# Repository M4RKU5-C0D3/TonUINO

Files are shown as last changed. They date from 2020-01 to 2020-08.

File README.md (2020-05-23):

# TonUINO
Die DIY Musikbox (nicht nur) für Kinder

# Change Log

## Version 2.1 (xx.xx.xxxx) noch WIP
- Partymodus hat nun eine Queue -> jedes Lied kommt nur genau 1x vorkommt
- Neue Wiedergabe-Modi "Spezialmodus Von-Bis" - Hörspiel, Album und Party -> erlaubt z.B. verschiedene Alben in einem Ordner zu haben und je mit einer Karte zu verknüpfen
- Admin-Menü
- Maximale, Minimale und Initiale Lautstärke
- Karten werden nun über das Admin-Menü neu konfiguriert
- die Funktion der Lautstärketasten (lauter/leiser oder vor/zurück) kann im Adminmenü vertauscht werden
- Shortcuts können konfiguriert werden!
- Support für 5 Knöpfe hinzugefügt
- Reset der Einstellungen ins Adminmenü verschoben
- Modikationskarten (Sleeptimer, Tastensperre, Stopptanz, KiTa-Modus)
- Admin-Menü kann abgesichert werden

## Version 2.01 (01.11.2018)
- kleiner Fix um die Probleme beim Anlernen von Karten zu reduzieren

## Version 2.0 (26.08.2018)

- Lautstärke wird nun über einen langen Tastendruck geändert
- bei kurzem Tastendruck wird der nächste / vorherige Track abgespielt (je nach Wiedergabemodus nicht verfügbar)
- Während der Wiedergabe wird bei langem Tastendruck auf Play/Pause die Nummer des aktuellen Tracks angesagt
- Neuer Wiedergabemodus: **Einzelmodus**
  Eine Karte kann mit einer einzelnen Datei aus einem Ordner verknüpft werden. Dadurch sind theoretisch 25000 verschiedene Karten für je eine Datei möglich
- Neuer Wiedergabemodus: **Hörbuch-Modus**
  Funktioniert genau wie der Album-Modus. Zusätzlich wir der Fortschritt im EEPROM des Arduinos gespeichert und beim nächsten mal wird bei der jeweils letzten Datei neu gestartet. Leider kann nur der Track, nicht die Stelle im Track gespeichert werden
- Um mehr als 100 Karten zu unterstützen wird die Konfiguration der Karten nicht mehr im EEPROM gespeichert sondern direkt auf den Karten - die Karte muss daher beim Anlernen aufgelegt bleiben!
- Durch einen langen Druck auf Play/Pause kann **eine Karte neu konfiguriert** werden
- In den Auswahldialogen kann durch langen Druck auf die Lautstärketasten jeweils um 10 Ordner oder Dateien vor und zurück gesprungen werden
- Reset des MP3 Moduls beim Start entfernt - war nicht nötig und hat "Krach" gemacht

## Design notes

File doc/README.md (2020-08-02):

# LENIBOX

## Einkaufsliste

* [Metall Druckknöpfe](https://www.ebay.de/itm/163190164725) ✔️
* [USB Buchse](https://www.ebay.de/itm/252855078960) ✔️
* [RC522 RFID Modul](https://www.ebay.de/itm/272387195008) ✔️
* ~~[RC522 RFID Karten](https://www.ebay.de/itm/273026026604) ⏰~~
* [RC522 RFID Karten](https://www.reichelt.de/entwicklerboards-rfid-card-fuer-modul-rc522-debo-rfid-card-p201860.html)✔️
* ~~[18650 USB Battery Shield V8](https://www.ebay.de/itm/273652614725) ✔️~~
* [18650 USB Battery Shield V8](https://de.aliexpress.com/item/4000870234968.html) ⏰
* [18650 Akkus](https://www.ebay.de/itm/112787034818) ✔️
* [Drehpotentiometer](https://www.ebay.de/itm/153336494885) ✔️
* [Latstärkeknopf](https://www.ebay.de/itm/333283346990) ✔️
* [Visaton FR 10 HM](https://www.amazon.de/gp/product/B003A65O7U/) ✔️

## Zubehör

* [Lochrasterplatine](https://www.reichelt.de/lochrasterplatine-hartpapier-500x100mm-h25pr500-p8274.html) ✔️
* [Platinen-Steckverbinder](https://www.reichelt.de/platinen-steckverbinder-c7525.html) ✔️
* [Messing Abstandhalter M3](https://www.ebay.de/sch/i.html?_nkw=Messing+M3+Abstandhalter+Set) ✔️
* [Kabel](https://www.ebay.de/itm/302766474820) ✔️
* [Flachsteckhülsen](https://www.ebay.de/itm/152880177973) ✔️

## Datenblätter & Anleitungen

* [TonUINO](https://discourse.voss.earth/t/uebersicht-der-bedienung-tonuino/2072)
* [Visaton FR 10 HM](https://www.visaton.de/de/produkte/chassiszubehoer/breitband-systeme/fr-10-8-ohm)

## Makuna/DFMiniMp3

* "Com Error": [Codes](https://github.com/Makuna/DFMiniMp3/wiki/Notification-Method#static-void-onerroruint16_t-errorcode)

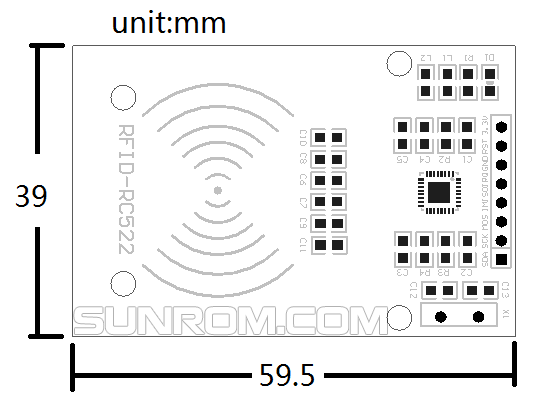
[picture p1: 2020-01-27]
doc/RC522.gif

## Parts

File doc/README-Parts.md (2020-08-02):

# LENIBOX - Bauteile

## Energieversorgung

Beitrag im [Forum](https://discourse.voss.earth/t/tutorial-bau-dir-deine-eigene-powerbank/744)

### Einkaufsliste

0. Step Up: MT3608
0. Lade Bord (USB 5V 1A 18650 Protection) : TC4056A / TP4056 / TP5000 / TP5100
0. Akku
0. Case

## NFC / RFID

### Einkaufsliste

0. Reader (RFID RC522 13,56 MHz MIFARE) : RC522

## MP3

### Einkaufsliste

0. SD Card Board :

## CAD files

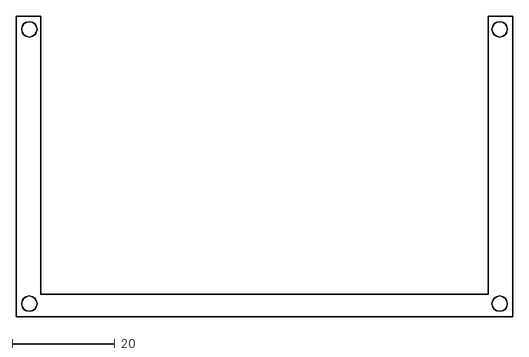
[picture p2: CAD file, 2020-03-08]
cad/card-pocket-lower.dxf
96.5 x 58.4

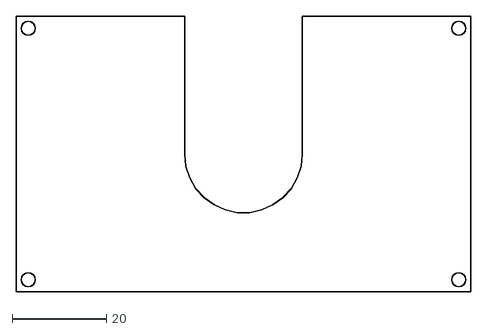
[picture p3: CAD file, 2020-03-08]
cad/card-pocket-upper.dxf
96.5 x 58.4

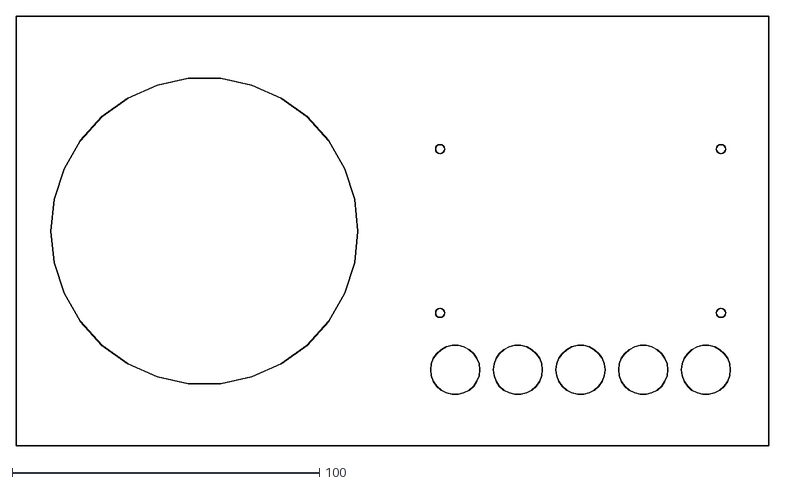
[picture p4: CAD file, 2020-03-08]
cad/front.dxf
245.0 x 140.0

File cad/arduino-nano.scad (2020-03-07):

include <metrics.scad>;

module ARDUINO(){
    color("SteelBlue")cube([17*2.54,7*2.54,1]);
    color("LightGrey")for(X = [2.54/2*3 : 2.54 : 17*2.54-2.54/2*3]){
        translate([X,2.54/2,-3])cylinder(3,0.5,0.5);
    }
}

ARDUINO();

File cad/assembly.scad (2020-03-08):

include <metrics.scad>;

use <card-pocket-lower.scad>
use <card-pocket-upper.scad>
use <pcb.scad>
use <front.scad>

module Assembly(){
  // FRONT
  Front();
  // POCKET
  translate([FW/4*3-PW/2,FH/2-PH/2,FT+0.001]){
    translate([0,0,0])CardPocketLower();
    translate([0,0,PT+0.001])CardPocketUpper();
  }
  // PCB
  translate([FW/4*3-PW/2,FH/2-PH/2,-10]) PCB();
  // BUTTONS
  for(BX = [FW/2+FW/12:FW/12:FW-FW/12]){
    translate([BX,(FH/2-PH/2-FB),0]){
      color("Lime")cylinder(FT+2,FB/2+1,FB/2+1);
      color("LimeGreen")cylinder(FT+4,FB/2-2,FB/2-2);
    }
  }
  // SPEAKER
  color("DimGray")
    translate([(FW/4),(FH/2),0])
      cylinder(1,(FS/2),(FS/2));
}

Assembly();

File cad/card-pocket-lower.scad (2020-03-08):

include <metrics.scad>;

use <card-pocket-upper.scad>;

module CardPocketLower(){
    difference(){
        CardPocketUpper();
        //CUTOUT
        translate([(PW-CW-PP)/2,PH-CH,-1])cube([CW+2,CH+1,PT+PP]);
    }
}

projection(cut = true)CardPocketLower();

echo(str("CardPocketLower: ",PW,"x",PH,"x",PT,"mm"));

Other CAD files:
cad/card-pocket-upper.scad
cad/front.scad
cad/metrics.scad
cad/pcb.scad

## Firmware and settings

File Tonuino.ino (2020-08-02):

#include <DFMiniMp3.h>
#include <EEPROM.h>
#include <JC_Button.h>
#include <MFRC522.h>
#include <SPI.h>
#include <SoftwareSerial.h>
#include <avr/sleep.h>

/*
   _____         _____ _____ _____ _____
  |_   _|___ ___|  |  |     |   | |     |
    | | | . |   |  |  |-   -| | | |  |  |
    |_| |___|_|_|_____|_____|_|___|_____|
    TonUINO Version 2.1

    created by Thorsten Voß and licensed under GNU/GPL.
    Information and contribution at https://tonuino.de.
*/

// uncomment the below line to enable five button support
//#define FIVEBUTTONS

static const uint32_t cardCookie = 322417479;

// DFPlayer Mini
SoftwareSerial mySoftwareSerial(2, 3); // RX, TX
uint16_t numTracksInFolder;
uint16_t currentTrack;
uint16_t firstTrack;
uint8_t queue[255];
uint8_t volume;

struct folderSettings {
  uint8_t folder;
  uint8_t mode;
  uint8_t special;
  uint8_t special2;
};

// this object stores nfc tag data
struct nfcTagObject {
  uint32_t cookie;
  uint8_t version;
  folderSettings nfcFolderSettings;
  //  uint8_t folder;
  //  uint8_t mode;
  //  uint8_t special;
  //  uint8_t special2;
};

// admin settings stored in eeprom
struct adminSettings {
  uint32_t cookie;
  byte version;
  uint8_t maxVolume;
  uint8_t minVolume;
  uint8_t initVolume;
  uint8_t eq;
  bool locked;
  long standbyTimer;
  bool invertVolumeButtons;
  folderSettings shortCuts[4];
  uint8_t adminMenuLocked;
  uint8_t adminMenuPin[4];
};

adminSettings mySettings;
nfcTagObject myCard;
folderSettings *myFolder;
unsigned long sleepAtMillis = 0;
static uint16_t _lastTrackFinished;

static void nextTrack(uint16_t track);
uint8_t voiceMenu(int numberOfOptions, int startMessage, int messageOffset,
                  bool preview = false, int previewFromFolder = 0, int defaultValue = 0, bool exitWithLongPress = false);
bool isPlaying();
bool checkTwo ( uint8_t a[], uint8_t b[] );
void writeCard(nfcTagObject nfcTag);
void dump_byte_array(byte * buffer, byte bufferSize);
void adminMenu(bool fromCard = false);
bool knownCard = false;

// implement a notification class,
// its member methods will get called
//
class Mp3Notify {
  public:
    static void OnError(uint16_t errorCode) {
      // see DfMp3_Error for code meaning
      Serial.println();
      Serial.print("Com Error ");
      Serial.println(errorCode);
    }
    static void PrintlnSourceAction(DfMp3_PlaySources source, const char* action) {
      if (source & DfMp3_PlaySources_Sd) Serial.print("SD Karte ");
      if (source & DfMp3_PlaySources_Usb) Serial.print("USB ");
      if (source & DfMp3_PlaySources_Flash) Serial.print("Flash ");
      Serial.println(action);
    }
    static void OnPlayFinished(DfMp3_PlaySources source, uint16_t track) {
      //      Serial.print("Track beendet");
      //      Serial.println(track);
      //      delay(100);
      nextTrack(track);
    }
    static void OnPlaySourceOnline(DfMp3_PlaySources source) {
      PrintlnSourceAction(source, "online");
    }
    static void OnPlaySourceInserted(DfMp3_PlaySources source) {
      PrintlnSourceAction(source, "bereit");
    }
    static void OnPlaySourceRemoved(DfMp3_PlaySources source) {
      PrintlnSourceAction(source, "entfernt");
    }
};

static DFMiniMp3<SoftwareSerial, Mp3Notify> mp3(mySoftwareSerial);

void shuffleQueue() {
  // Queue für die Zufallswiedergabe erstellen
  for (uint8_t x = 0; x < numTracksInFolder - firstTrack + 1; x++)
    queue[x] = x + firstTrack;
  // Rest mit 0 auffüllen
  for (uint8_t x = numTracksInFolder - firstTrack + 1; x < 255; x++)
    queue[x] = 0;
  // Queue mischen
  for (uint8_t i = 0; i < numTracksInFolder - firstTrack + 1; i++)
  {
    uint8_t j = random (0, numTracksInFolder - firstTrack + 1);
    uint8_t t = queue[i];
    queue[i] = queue[j];
    queue[j] = t;
  }
  /*  Serial.println(F("Queue :"));
    for (uint8_t x = 0; x < numTracksInFolder - firstTrack + 1 ; x++)
      Serial.println(queue[x]);
  */
}

void writeSettingsToFlash() {
  Serial.println(F("=== writeSettingsToFlash()"));
  int address = sizeof(myFolder->folder) * 100;
  EEPROM.put(address, mySettings);
}

void resetSettings() {
  Serial.println(F("=== resetSettings()"));
  mySettings.cookie = cardCookie;
  mySettings.version = 2;
  mySettings.maxVolume = 25;
  mySettings.minVolume = 5;
  mySettings.initVolume = 15;
  mySettings.eq = 1;
  mySettings.locked = false;
  mySettings.standbyTimer = 0;
  mySettings.invertVolumeButtons = true;
  mySettings.shortCuts[0].folder = 0;
  mySettings.shortCuts[1].folder = 0;
  mySettings.shortCuts[2].folder = 0;
  mySettings.shortCuts[3].folder = 0;
  mySettings.adminMenuLocked = 0;
  mySettings.adminMenuPin[0] = 1;
  mySettings.adminMenuPin[1] = 1;
  mySettings.adminMenuPin[2] = 1;
  mySettings.adminMenuPin[3] = 1;

  writeSettingsToFlash();
}

void migrateSettings(int oldVersion) {
  if (oldVersion == 1) {
    Serial.println(F("=== resetSettings()"));
    Serial.println(F("1 -> 2"));
    mySettings.version = 2;
    mySettings.adminMenuLocked = 0;
    mySettings.adminMenuPin[0] = 1;
    mySettings.adminMenuPin[1] = 1;
    mySettings.adminMenuPin[2] = 1;
    mySettings.adminMenuPin[3] = 1;
    writeSettingsToFlash();
  }
}

void loadSettingsFromFlash() {
  Serial.println(F("=== loadSettingsFromFlash()"));
  int address = sizeof(myFolder->folder) * 100;
  EEPROM.get(address, mySettings);
  if (mySettings.cookie != cardCookie)
    resetSettings();
  migrateSettings(mySettings.version);

  Serial.print(F("Version: "));
  Serial.println(mySettings.version);

  Serial.print(F("Maximal Volume: "));
  Serial.println(mySettings.maxVolume);

  Serial.print(F("Minimal Volume: "));
  Serial.println(mySettings.minVolume);

  Serial.print(F("Initial Volume: "));
  Serial.println(mySettings.initVolume);

  Serial.print(F("EQ: "));
  Serial.println(mySettings.eq);

  Serial.print(F("Locked: "));
  Serial.println(mySettings.locked);

  Serial.print(F("Sleep Timer: "));
  Serial.println(mySettings.standbyTimer);

  Serial.print(F("Inverted Volume Buttons: "));
  Serial.println(mySettings.invertVolumeButtons);

  Serial.print(F("Admin Menu locked: "));
  Serial.println(mySettings.adminMenuLocked);

  Serial.print(F("Admin Menu Pin: "));
  Serial.print(mySettings.adminMenuPin[0]);
  Serial.print(mySettings.adminMenuPin[1]);
  Serial.print(mySettings.adminMenuPin[2]);
  Serial.println(mySettings.adminMenuPin[3]);
}

class Modifier {
  public:
    virtual void loop() {}
    virtual bool handlePause() {
      return false;
    }
    virtual bool handleNext() {
      return false;
    }
    virtual bool handlePrevious() {
      return false;
    }
    virtual bool handleNextButton() {
      return false;
    }
    virtual bool handlePreviousButton() {
      return false;
    }
    virtual bool handleVolumeUp() {
      return false;
    }
    virtual bool handleVolumeDown() {
      return false;
    }
    virtual bool handleRFID(nfcTagObject *newCard) {
      return false;
    }
    virtual uint8_t getActive() {
      return 0;
    }
    Modifier() {

    }
};

Modifier *activeModifier = NULL;

class SleepTimer: public Modifier {
  private:
    unsigned long sleepAtMillis = 0;

  public:
    void loop() {
      if (this->sleepAtMillis != 0 && millis() > this->sleepAtMillis) {
        Serial.println(F("=== SleepTimer::loop() -> SLEEP!"));
        mp3.pause();
        setstandbyTimer();
        activeModifier = NULL;
        delete this;
      }
    }

    SleepTimer(uint8_t minutes) {
      Serial.println(F("=== SleepTimer()"));
      Serial.println(minutes);
      this->sleepAtMillis = millis() + minutes * 60000;
      //      if (isPlaying())
      //        mp3.playAdvertisement(302);
      //      delay(500);
    }
    uint8_t getActive() {
      Serial.println(F("== SleepTimer::getActive()"));
      return 1;
    }
};

class FreezeDance: public Modifier {
  private:
    unsigned long nextStopAtMillis = 0;
    const uint8_t minSecondsBetweenStops = 5;
    const uint8_t maxSecondsBetweenStops = 30;

    void setNextStopAtMillis() {
      uint16_t seconds = random(this->minSecondsBetweenStops, this->maxSecondsBetweenStops + 1);
      Serial.println(F("=== FreezeDance::setNextStopAtMillis()"));
      Serial.println(seconds);
      this->nextStopAtMillis = millis() + seconds * 1000;
    }

  public:
    void loop() {
      if (this->nextStopAtMillis != 0 && millis() > this->nextStopAtMillis) {
        Serial.println(F("== FreezeDance::loop() -> FREEZE!"));
        if (isPlaying()) {
          mp3.playAdvertisement(301);
          delay(500);
        }
        setNextStopAtMillis();
      }
    }
    FreezeDance(void) {
      Serial.println(F("=== FreezeDance()"));
      if (isPlaying()) {
        delay(1000);
        mp3.playAdvertisement(300);
        delay(500);
      }
      setNextStopAtMillis();
    }
    uint8_t getActive() {
      Serial.println(F("== FreezeDance::getActive()"));
      return 2;
    }
};

class Locked: public Modifier {
  public:
    virtual bool handlePause()     {
      Serial.println(F("== Locked::handlePause() -> LOCKED!"));
      return true;
    }
    virtual bool handleNextButton()       {
      Serial.println(F("== Locked::handleNextButton() -> LOCKED!"));
      return true;
    }
    virtual bool handlePreviousButton() {
      Serial.println(F("== Locked::handlePreviousButton() -> LOCKED!"));
      return true;
    }
    virtual bool handleVolumeUp()   {
      Serial.println(F("== Locked::handleVolumeUp() -> LOCKED!"));
      return true;
    }
    virtual bool handleVolumeDown() {
      Serial.println(F("== Locked::handleVolumeDown() -> LOCKED!"));
      return true;
    }
    virtual bool handleRFID(nfcTagObject *newCard) {
      Serial.println(F("== Locked::handleRFID() -> LOCKED!"));
      return true;
    }
    Locked(void) {
      Serial.println(F("=== Locked()"));
      //      if (isPlaying())
      //        mp3.playAdvertisement(303);
    }
    uint8_t getActive() {
      return 3;
    }
};

class ToddlerMode: public Modifier {
  public:
    virtual bool handlePause()     {
      Serial.println(F("== ToddlerMode::handlePause() -> LOCKED!"));
      return true;
    }
    virtual bool handleNextButton()       {
      Serial.println(F("== ToddlerMode::handleNextButton() -> LOCKED!"));
      return true;
    }
    virtual bool handlePreviousButton() {
      Serial.println(F("== ToddlerMode::handlePreviousButton() -> LOCKED!"));
      return true;
    }
    virtual bool handleVolumeUp()   {
      Serial.println(F("== ToddlerMode::handleVolumeUp() -> LOCKED!"));
      return true;
    }
    virtual bool handleVolumeDown() {
      Serial.println(F("== ToddlerMode::handleVolumeDown() -> LOCKED!"));
      return true;
    }
    ToddlerMode(void) {
      Serial.println(F("=== ToddlerMode()"));
      //      if (isPlaying())
      //        mp3.playAdvertisement(304);
    }
    uint8_t getActive() {
      Serial.println(F("== ToddlerMode::getActive()"));
      return 4;
    }
};

class KindergardenMode: public Modifier {
  private:
    nfcTagObject nextCard;
    bool cardQueued = false;

  public:
    virtual bool handleNext() {
      Serial.println(F("== KindergardenMode::handleNext() -> NEXT"));
      //if (this->nextCard.cookie == cardCookie && this->nextCard.nfcFolderSettings.folder != 0 && this->nextCard.nfcFolderSettings.mode != 0) {
      //myFolder = &this->nextCard.nfcFolderSettings;
      if (this->cardQueued == true) {
        this->cardQueued = false;

        myCard = nextCard;
        myFolder = &myCard.nfcFolderSettings;
        Serial.println(myFolder->folder);
        Serial.println(myFolder->mode);
        playFolder();
        return true;
      }
      return false;
    }
    //    virtual bool handlePause()     {
    //      Serial.println(F("== KindergardenMode::handlePause() -> LOCKED!"));
    //      return true;
    //    }
    virtual bool handleNextButton()       {
      Serial.println(F("== KindergardenMode::handleNextButton() -> LOCKED!"));
      return true;
    }
    virtual bool handlePreviousButton() {
      Serial.println(F("== KindergardenMode::handlePreviousButton() -> LOCKED!"));
      return true;
    }
    virtual bool handleRFID(nfcTagObject * newCard) { // lot of work to do!
      Serial.println(F("== KindergardenMode::handleRFID() -> queued!"));
      this->nextCard = *newCard;
      this->cardQueued = true;
      if (!isPlaying()) {
        handleNext();
      }
      return true;
    }
    KindergardenMode() {
      Serial.println(F("=== KindergardenMode()"));
      //      if (isPlaying())
      //        mp3.playAdvertisement(305);
      //      delay(500);
    }
    uint8_t getActive() {
      Serial.println(F("== KindergardenMode::getActive()"));
      return 5;
    }
};

class RepeatSingleModifier: public Modifier {
  public:
    virtual bool handleNext() {
      Serial.println(F("== RepeatSingleModifier::handleNext() -> REPEAT CURRENT TRACK"));
      delay(50);
      if (isPlaying()) return true;
      mp3.playFolderTrack(myFolder->folder, currentTrack);
      _lastTrackFinished = 0;
      return true;
    }
    RepeatSingleModifier() {
      Serial.println(F("=== RepeatSingleModifier()"));
    }
    uint8_t getActive() {
      Serial.println(F("== RepeatSingleModifier::getActive()"));
      return 6;
    }
};

// An modifier can also do somethings in addition to the modified action
// by returning false (not handled) at the end
// This simple FeedbackModifier will tell the volume before changing it and
// give some feedback once a RFID card is detected.
class FeedbackModifier: public Modifier {
  public:
    virtual bool handleVolumeDown() {
      if (volume > mySettings.minVolume) {
        mp3.playAdvertisement(volume - 1);
      }
      else {
        mp3.playAdvertisement(volume);
      }
      delay(500);
      Serial.println(F("== FeedbackModifier::handleVolumeDown()!"));
      return false;
    }
    virtual bool handleVolumeUp() {
      if (volume < mySettings.maxVolume) {
        mp3.playAdvertisement(volume + 1);
      }
      else {
        mp3.playAdvertisement(volume);
      }
      delay(500);
      Serial.println(F("== FeedbackModifier::handleVolumeUp()!"));
      return false;
    }
    virtual bool handleRFID(nfcTagObject *newCard) {
      Serial.println(F("== FeedbackModifier::handleRFID()"));
      return false;
    }
};
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
void loop() {
  do {
    checkStandbyAtMillis();
    mp3.loop();

    // Modifier : WIP!
    if (activeModifier != NULL) {
      activeModifier->loop();
    }

    // Buttons werden nun über JS_Button gehandelt, dadurch kann jede Taste
    // doppelt belegt werden
    readButtons();

    volumeAnalogKnob();

    // admin menu
    if ((pauseButton.pressedFor(LONG_PRESS) || upButton.pressedFor(LONG_PRESS) || downButton.pressedFor(LONG_PRESS)) && pauseButton.isPressed() && upButton.isPressed() && downButton.isPressed()) {
      mp3.pause();
      do {
        readButtons();
      } while (pauseButton.isPressed() || upButton.isPressed() || downButton.isPressed());
      readButtons();
      adminMenu();
      break;
    }

    if (pauseButton.wasReleased()) {
      if (activeModifier != NULL)
        if (activeModifier->handlePause() == true)
          return;
      if (ignorePauseButton == false)
        if (isPlaying()) {
          mp3.pause();
          setstandbyTimer();
        }
        else if (knownCard) {
          mp3.start();
          disablestandbyTimer();
        }
      ignorePauseButton = false;
    } else if (pauseButton.pressedFor(LONG_PRESS) &&
               ignorePauseButton == false) {
      if (activeModifier != NULL)
        if (activeModifier->handlePause() == true)
          return;
      if (isPlaying()) {
        uint8_t advertTrack;
        if (myFolder->mode == 3 || myFolder->mode == 9) {
          advertTrack = (queue[currentTrack - 1]);
        }
        else {
          advertTrack = currentTrack;
        }
        // Spezialmodus Von-Bis für Album und Party gibt die Dateinummer relativ zur Startposition wieder
        if (myFolder->mode == 8 || myFolder->mode == 9) {
          advertTrack = advertTrack - myFolder->special + 1;
        }
        mp3.playAdvertisement(advertTrack);
      }
      else {
        playShortCut(0);
      }
      ignorePauseButton = true;
    }

    if (upButton.pressedFor(LONG_PRESS)) {
#ifndef FIVEBUTTONS
      if (isPlaying()) {
        if (!mySettings.invertVolumeButtons) {
          volumeUpButton();
        }
        else {
          nextButton();
        }
      }
      else {
        playShortCut(1);
      }
      ignoreUpButton = true;
#endif
    } else if (upButton.wasReleased()) {
      if (!ignoreUpButton)
        if (!mySettings.invertVolumeButtons) {
          nextButton();
        }
        else {
          volumeUpButton();
        }
      ignoreUpButton = false;
    }

    if (downButton.pressedFor(LONG_PRESS)) {
#ifndef FIVEBUTTONS
      if (isPlaying()) {
        if (!mySettings.invertVolumeButtons) {
          volumeDownButton();
        }
        else {
          previousButton();
        }
      }
      else {
        playShortCut(2);
      }
      ignoreDownButton = true;
#endif
    } else if (downButton.wasReleased()) {
      if (!ignoreDownButton) {
        if (!mySettings.invertVolumeButtons) {
          previousButton();
        }
        else {
          volumeDownButton();
        }
      }
      ignoreDownButton = false;
    }
#ifdef FIVEBUTTONS
    if (buttonFour.wasReleased()) {
      if (isPlaying()) {
        if (!mySettings.invertVolumeButtons) {
          volumeUpButton();
        }
        else {
          nextButton();
        }
      }
      else {
        playShortCut(1);
      }
    }
    if (buttonFive.wasReleased()) {
      if (isPlaying()) {
        if (!mySettings.invertVolumeButtons) {
          volumeDownButton();
        }
        else {
          previousButton();
        }
      }
      else {
        playShortCut(2);
      }
    }
#endif
    // Ende der Buttons
  } while (!mfrc522.PICC_IsNewCardPresent());

  // RFID Karte wurde aufgelegt

  if (!mfrc522.PICC_ReadCardSerial())
    return;

  if (readCard(&myCard) == true) {
    if (myCard.cookie == cardCookie && myCard.nfcFolderSettings.folder != 0 && myCard.nfcFolderSettings.mode != 0) {
      playFolder();
    }

    // Neue Karte konfigurieren
    else if (myCard.cookie != cardCookie) {
      knownCard = false;
      mp3.playMp3FolderTrack(300);
      waitForTrackToFinish();
      setupCard();
    }
  }
  mfrc522.PICC_HaltA();
  mfrc522.PCD_StopCrypto1();

}

void adminMenu(bool fromCard = false) {
  disablestandbyTimer();
  mp3.pause();
  Serial.println(F("=== adminMenu()"));
  knownCard = false;
  if (fromCard == false) {
    // Admin menu has been locked - it still can be trigged via admin card
    if (mySettings.adminMenuLocked == 1) {
      return;
    }
    // Pin check
    else if (mySettings.adminMenuLocked == 2) {
      uint8_t pin[4];
      mp3.playMp3FolderTrack(991);
      if (askCode(pin) == true) {
        if (checkTwo(pin, mySettings.adminMenuPin) == false) {
          return;
        }
      } else {
        return;
      }
    }
    // Match check
    else if (mySettings.adminMenuLocked == 3) {
      uint8_t a = random(10, 20);
      uint8_t b = random(1, 10);
      uint8_t c;
      mp3.playMp3FolderTrack(992);
      waitForTrackToFinish();
      mp3.playMp3FolderTrack(a);

      if (random(1, 3) == 2) {
        // a + b
        c = a + b;
        waitForTrackToFinish();
        mp3.playMp3FolderTrack(993);
      } else {
        // a - b
        b = random(1, a);
        c = a - b;
        waitForTrackToFinish();
        mp3.playMp3FolderTrack(994);
      }
      waitForTrackToFinish();
      mp3.playMp3FolderTrack(b);
      Serial.println(c);
      uint8_t temp = voiceMenu(255, 0, 0, false);
      if (temp != c) {
        return;
      }
    }
  }
  int subMenu = voiceMenu(12, 900, 900, false, false, 0, true);
  if (subMenu == 0)
    return;
  if (subMenu == 1) {
    resetCard();
    mfrc522.PICC_HaltA();
    mfrc522.PCD_StopCrypto1();
  }
  else if (subMenu == 2) {
    // Maximum Volume
    mySettings.maxVolume = voiceMenu(30 - mySettings.minVolume, 930, mySettings.minVolume, false, false, mySettings.maxVolume - mySettings.minVolume) + mySettings.minVolume;
  }
  else if (subMenu == 3) {
    // Minimum Volume
    mySettings.minVolume = voiceMenu(mySettings.maxVolume - 1, 931, 0, false, false, mySettings.minVolume);
  }
  else if (subMenu == 4) {
    // Initial Volume
    mySettings.initVolume = voiceMenu(mySettings.maxVolume - mySettings.minVolume + 1, 932, mySettings.minVolume - 1, false, false, mySettings.initVolume - mySettings.minVolume + 1) + mySettings.minVolume - 1;
  }
  else if (subMenu == 5) {
    // EQ
    mySettings.eq = voiceMenu(6, 920, 920, false, false, mySettings.eq);
    mp3.setEq(mySettings.eq - 1);
  }
  else if (subMenu == 6) {
    // create modifier card
    nfcTagObject tempCard;
    tempCard.cookie = cardCookie;
    tempCard.version = 1;
    tempCard.nfcFolderSettings.folder = 0;
    tempCard.nfcFolderSettings.special = 0;
    tempCard.nfcFolderSettings.special2 = 0;
    tempCard.nfcFolderSettings.mode = voiceMenu(6, 970, 970, false, false, 0, true);

    if (tempCard.nfcFolderSettings.mode != 0) {
      if (tempCard.nfcFolderSettings.mode == 1) {
        switch (voiceMenu(4, 960, 960)) {
          case 1: tempCard.nfcFolderSettings.special = 5; break;
          case 2: tempCard.nfcFolderSettings.special = 15; break;
          case 3: tempCard.nfcFolderSettings.special = 30; break;
          case 4: tempCard.nfcFolderSettings.special = 60; break;
        }
      }
      mp3.playMp3FolderTrack(800);
      do {
        readButtons();
        if (upButton.wasReleased() || downButton.wasReleased()) {
          Serial.println(F("Abgebrochen!"));
          mp3.playMp3FolderTrack(802);
          return;
        }
      } while (!mfrc522.PICC_IsNewCardPresent());
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

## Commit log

2019-11-16 add concept files
    [Sketch.fzz]
2020-01-19 add documentation
    [Sketch.fzz]
2020-01-19 remove dulicates
    [Sketch.fzz]
2020-01-27 add doc
    [front.scad]
2020-03-07 add arduino
    [arduino-nano.scad]
2020-03-08 introduce assembly + add dxf
    [assembly.scad, card-pocket-lower.dxf, card-pocket-lower.scad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]
2020-05-17 switch to original code
2020-05-17 adjust intellisense to arduino
